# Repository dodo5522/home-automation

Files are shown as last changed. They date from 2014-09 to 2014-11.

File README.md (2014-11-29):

# Home automation

This repository is for my home automation by using Raspberry Pi and Arduino.  
The automated gardening is working now.  
Another function does not work yet.  

# System design

* Gardening monitoring
    * Written on [Qiita site](http://qiita.com/dodo5522/items/63d1efee3f70b3d5f2f6) in Japanese.
* Solar power monitoring
    * Under implementing.

# Directory structure

* documents
    * Overview, Schematics, etc.
* nodes
    * C/C++ source code working on Arduino.
    * All node will have Arduino and XBee.
* server 
    * Python source code working on Raspberry Pi.
    * Raspberry Pi will work as server to gather the all information sent by all node.

# How to use

1. Raspberry Pi as XBee cordinator
    1. Locate 'setting.conf' with below values.

            $ cat /etc/home-automation/setting.conf
            [rpiuartreceiver]
            port = /dev/ttyAMA0
            baurate = 9600
            [vegetablesplantermonitor]
            address = 0x0013a20040b44f84
            xively_api_key = xxx
            xively_feed = yyy

    2. Run the blew commands.

            $ git clone https://github.com/dodo5522/home-automation
            $ cd ./home-automation
            $ ./setup.sh
            $ sudo /etc/init.d/home-automation start

2. Arduino with XBee router
    1. Use Arduino IDE 1.5.8 or later.
    2. Add c++11 flag on Arduino toolchain setting files. You can find the file like below.

            $ find /Applications/Arduino.app -name platform.txt
            /Applications/Arduino.app/Contents/Resources/Java/hardware/arduino/avr/platform.txt
            /Applications/Arduino.app/Contents/Resources/Java/hardware/arduino/sam/platform.txt

    3. Add flag setting onto both of the above setting file.

            --- origin.txt	2014-11-03 01:01:18.000000000 +0900
            +++ modify.txt	2014-11-03 01:01:03.000000000 +0900
            @@ -17,7 +17,7 @@
             compiler.c.elf.flags=-Os -Wl,--gc-sections
             compiler.S.flags=-c -g -x assembler-with-cpp
             compiler.cpp.cmd=arm-none-eabi-g++
            -compiler.cpp.flags=-c -g -Os -w -ffunction-sections -fdata-sections -nostdlib -fno-threadsafe-statics --param max-inline-insns-single=500 -fno-rtti -fno-exceptions -Dprintf=iprintf
            +compiler.cpp.flags=-std=gnu++11 -c -g -Os -w -ffunction-sections -fdata-sections -nostdlib -fno-threadsafe-statics --param max-inline-insns-single=500 -fno-rtti -fno-exceptions -Dprintf=iprintf
             compiler.ar.cmd=arm-none-eabi-ar
             compiler.ar.flags=rcs
             compiler.objcopy.cmd=arm-none-eabi-objcopy

    4. Build and program Arduino with gardening or powerplant library.

# Sequence flow

* server
    * Initialization and termination  
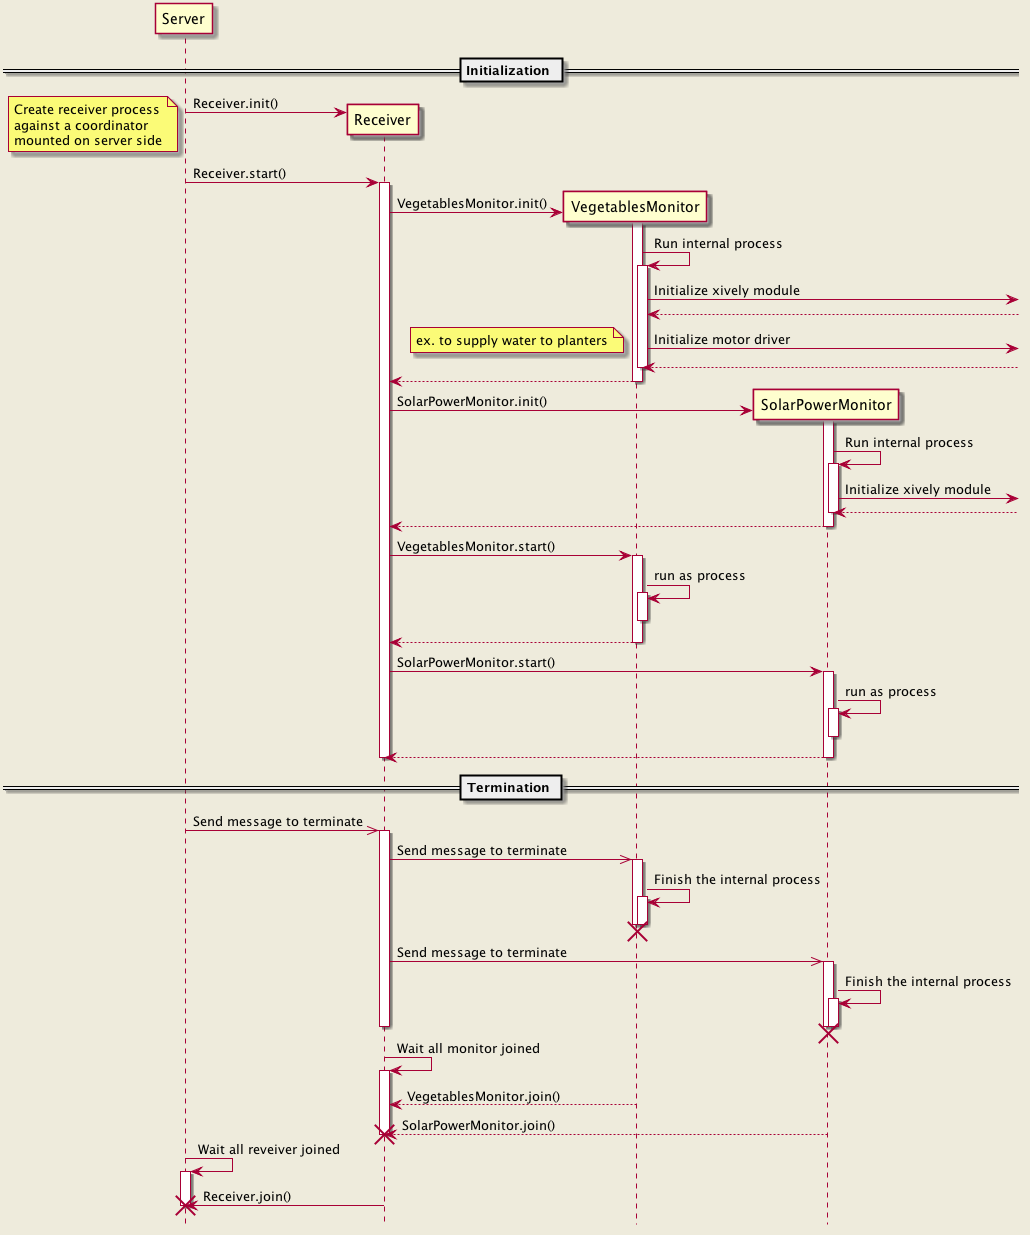
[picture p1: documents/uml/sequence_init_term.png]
initialize and terminate sequence flow
    
    * Monitoring nodes  
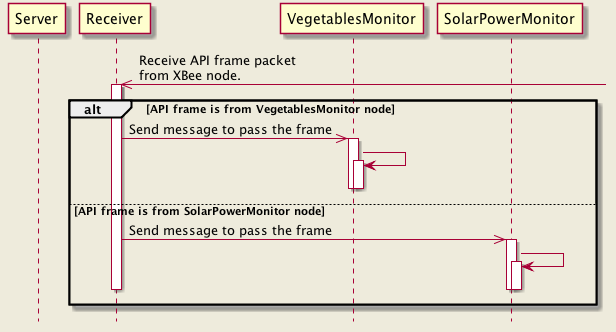
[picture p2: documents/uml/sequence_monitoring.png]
monitoring nodes


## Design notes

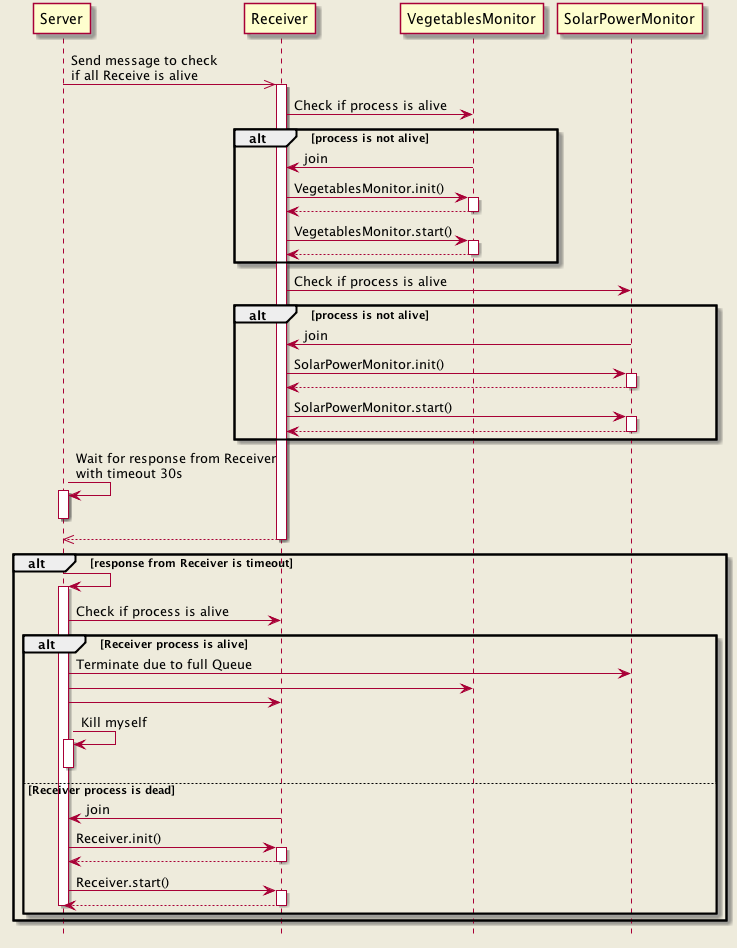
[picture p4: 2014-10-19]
documents/uml/sequence_check_alive.png

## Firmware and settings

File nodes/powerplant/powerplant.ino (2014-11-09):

/*
 Example code for my solar plant monitor.
 Editor     : Takashi Ando
 Version    : 1.0
*/
#include <Wire.h>
#include <INA226.h>
#include <Adafruit_INA219.h>
#include <XBee.h>
#include <datatype.h>
#include "powerplant.h"

#if defined(ENABLE_DEBUG_SOFT_SERIAL)
#include <SoftwareSerial.h>
#endif
#include <debug.h>

/****************************
 * IElectricPower class implementation
 ****************************/
IElectricPower::IElectricPower(char *name)
{
    strncpy(name_, name, sizeof(name_) - 1);
}

void IElectricPower::showConfig(void)
{
    DEBUG_PRINT("Name:                  "); DEBUG_PRINT(name_); DEBUG_PRINT("\n");
    DEBUG_PRINT("Measure current        "); DEBUG_PRINT(hasAvilityCurrent()); DEBUG_PRINT("\n");
    DEBUG_PRINT("Measure voltage        "); DEBUG_PRINT(hasAvilityVoltage()); DEBUG_PRINT("\n");
}

/****************************
 * MyINA226 class implementation
 ****************************/
MyINA226::MyINA226(char *name,
        uint8_t slave_address,
        float rShuntValueOhm,
        float iMaxExceptedCurrent_A,
        ina226_averages_t averages,
        ina226_busConvTime_t busConvTime,
        ina226_shuntConvTime_t shuntConvTime,
        ina226_mode_t mode)
    :IElectricPower(name),
    ina_(),
    slave_address_(slave_address),
    averages_(averages),
    busConvTime_(busConvTime),
    mode_(mode),
    rShuntValueOhm_(rShuntValueOhm),
    iMaxExceptedCurrent_A_(iMaxExceptedCurrent_A)
{
}

void MyINA226::begin(void)
{
    ina_.begin(slave_address_);
    ina_.configure(averages_, busConvTime_, shuntConvTime_, mode_);
    ina_.calibrate(rShuntValueOhm_, iMaxExceptedCurrent_A_);
}

void MyINA226::showConfig(void)
{
    IElectricPower::showConfig();
    DEBUG_PRINT("Mode:                  ");
    switch (ina_.getMode())
    {
        case INA226_MODE_POWER_DOWN:      DEBUG_PRINT("Power-Down\n"); break;
        case INA226_MODE_SHUNT_TRIG:      DEBUG_PRINT("Shunt Voltage, Triggered\n"); break;
        case INA226_MODE_BUS_TRIG:        DEBUG_PRINT("Bus Voltage, Triggered\n"); break;
        case INA226_MODE_SHUNT_BUS_TRIG:  DEBUG_PRINT("Shunt and Bus, Triggered\n"); break;
        case INA226_MODE_ADC_OFF:         DEBUG_PRINT("ADC Off\n"); break;
        case INA226_MODE_SHUNT_CONT:      DEBUG_PRINT("Shunt Voltage, Continuous\n"); break;
        case INA226_MODE_BUS_CONT:        DEBUG_PRINT("Bus Voltage, Continuous\n"); break;
        case INA226_MODE_SHUNT_BUS_CONT:  DEBUG_PRINT("Shunt and Bus, Continuous\n"); break;
        default: DEBUG_PRINT("unknown\n");
    }

    DEBUG_PRINT("Samples average:       ");
    switch (ina_.getAverages())
    {
        case INA226_AVERAGES_1:           DEBUG_PRINT("1 sample\n"); break;
        case INA226_AVERAGES_4:           DEBUG_PRINT("4 samples\n"); break;
        case INA226_AVERAGES_16:          DEBUG_PRINT("16 samples\n"); break;
        case INA226_AVERAGES_64:          DEBUG_PRINT("64 samples\n"); break;
        case INA226_AVERAGES_128:         DEBUG_PRINT("128 samples\n"); break;
        case INA226_AVERAGES_256:         DEBUG_PRINT("256 samples\n"); break;
        case INA226_AVERAGES_512:         DEBUG_PRINT("512 samples\n"); break;
        case INA226_AVERAGES_1024:        DEBUG_PRINT("1024 samples\n"); break;
        default: DEBUG_PRINT("unknown\n");
    }

    DEBUG_PRINT("Bus conversion time:   ");
    switch (ina_.getBusConversionTime())
    {
        case INA226_BUS_CONV_TIME_140US:  DEBUG_PRINT("140uS\n"); break;
        case INA226_BUS_CONV_TIME_204US:  DEBUG_PRINT("204uS\n"); break;
        case INA226_BUS_CONV_TIME_332US:  DEBUG_PRINT("332uS\n"); break;
        case INA226_BUS_CONV_TIME_588US:  DEBUG_PRINT("558uS\n"); break;
        case INA226_BUS_CONV_TIME_1100US: DEBUG_PRINT("1.100ms\n"); break;
        case INA226_BUS_CONV_TIME_2116US: DEBUG_PRINT("2.116ms\n"); break;
        case INA226_BUS_CONV_TIME_4156US: DEBUG_PRINT("4.156ms\n"); break;
        case INA226_BUS_CONV_TIME_8244US: DEBUG_PRINT("8.244ms\n"); break;
        default: DEBUG_PRINT("unknown\n");
    }

    DEBUG_PRINT("Shunt conversion time: ");
    switch (ina_.getShuntConversionTime())
    {
        case INA226_SHUNT_CONV_TIME_140US:  DEBUG_PRINT("140uS\n"); break;
        case INA226_SHUNT_CONV_TIME_204US:  DEBUG_PRINT("204uS\n"); break;
        case INA226_SHUNT_CONV_TIME_332US:  DEBUG_PRINT("332uS\n"); break;
        case INA226_SHUNT_CONV_TIME_588US:  DEBUG_PRINT("558uS\n"); break;
        case INA226_SHUNT_CONV_TIME_1100US: DEBUG_PRINT("1.100ms\n"); break;
        case INA226_SHUNT_CONV_TIME_2116US: DEBUG_PRINT("2.116ms\n"); break;
        case INA226_SHUNT_CONV_TIME_4156US: DEBUG_PRINT("4.156ms\n"); break;
        case INA226_SHUNT_CONV_TIME_8244US: DEBUG_PRINT("8.244ms\n"); break;
        default: DEBUG_PRINT("unknown\n");
    }

    DEBUG_PRINT("Max possible current:  "); DEBUG_PRINT(ina_.getMaxPossibleCurrent()); DEBUG_PRINT(" A\n");
    DEBUG_PRINT("Max current:           "); DEBUG_PRINT(ina_.getMaxCurrent());         DEBUG_PRINT(" A\n");
    DEBUG_PRINT("Max shunt voltage:     "); DEBUG_PRINT(ina_.getMaxShuntVoltage());    DEBUG_PRINT(" V\n");
    DEBUG_PRINT("Max power:             "); DEBUG_PRINT(ina_.getMaxPower());           DEBUG_PRINT(" W\n");
}

void MyINA226::showStatus(void)
{
    DEBUG_PRINT(name_);DEBUG_PRINT("\n");
    DEBUG_PRINT(" bus V: "); DEBUG_PRINT(getBusVoltage_V());   DEBUG_PRINT("\n");
    DEBUG_PRINT(" shu V: "); DEBUG_PRINT(getShuntVoltage_V()); DEBUG_PRINT("\n");
    DEBUG_PRINT(" shu A: "); DEBUG_PRINT(getShuntCurrent_A()); DEBUG_PRINT("\n");
    DEBUG_PRINT(" pwr W: "); DEBUG_PRINT(getBusPower_W());     DEBUG_PRINT("\n");
}

inline float MyINA226::getBusVoltage_V(void)
{
    return ina_.readBusVoltage();
}

inline float MyINA226::getShuntVoltage_V(void)
{
    return ina_.readShuntVoltage();
}

inline float MyINA226::getShuntCurrent_A(void)
{
    return ina_.readShuntCurrent();
}

inline float MyINA226::getBusPower_W(void)
{
    return ina_.readBusPower();
}

/****************************
 * MyINA219 class implementation
 ****************************/
MyINA219::MyINA219(char *name, uint8_t slave_address)
    :IElectricPower(name),
    ina_(slave_address)
{
}

void MyINA219::begin(void)
{
    ina_.begin();
}

void MyINA219::showStatus(void)
{
    DEBUG_PRINT(name_);DEBUG_PRINT("\n");
    DEBUG_PRINT(" bus V: "); DEBUG_PRINT(getBusVoltage_V());   DEBUG_PRINT("\n");
    DEBUG_PRINT(" shu V: "); DEBUG_PRINT(getShuntVoltage_V()); DEBUG_PRINT("\n");
    DEBUG_PRINT(" cur A: "); DEBUG_PRINT(getShuntCurrent_A()); DEBUG_PRINT("\n");
}

float MyINA219::getBusVoltage_V(void)
{
    return ina_.getBusVoltage_V();
}

float MyINA219::getShuntVoltage_V(void)
{
    return ina_.getShuntVoltage_mV()/1000.0;
}

float MyINA219::getShuntCurrent_A(void)
{
    return ina_.getCurrent_mA()/1000.0;
}

/****************************
 * Macro definition
 ****************************/
//const uint8_t INA226_ADDRESS  = 0x40;
const uint8_t INA226_11_ADDRESS = 0x45;
const uint8_t INA226_DD_ADDRESS = 0x4a;
const uint8_t INA226_CC_ADDRESS = 0x4f;

//const uint8_t INA219_ADDRESS    = 0x40;
const uint8_t INA219_A0_ADDRESS   = 0x41;
const uint8_t INA219_A1_ADDRESS   = 0x44;
const uint8_t INA219_A0A1_ADDRESS = 0x45;

const int LED_SWITCH_PIN = 2;

/****************************
 * global variables
 ****************************/
#if !defined(ENABLE_DEBUG_HARD_SERIAL)
static XBee myXBee = XBee();
static XBeeAddress64 addrContributor = XBeeAddress64(XBEE_ADDRESS_H_COORDINATOR, XBEE_ADDRESS_L_COORDINATOR);
#endif

static MyINA226 battery = MyINA226("battery", INA226_CC_ADDRESS);
static MyINA226 solar = MyINA226("solar panel", INA226_DD_ADDRESS);
//static MyINA219 conv = MyINA219("converter", INA219_A0A1_ADDRESS);

static IElectricPower *powerSensors[] =
{
    static_cast<IElectricPower*>(&battery),
    static_cast<IElectricPower*>(&solar),
//    static_cast<IElectricPower*>(&conv)
};

static unsigned long mainLoopInterval = MAIN_INTERVAL_MSEC;

/****************************
 * internal functions
 ****************************/
boolean isTriggerToPost(void)
{
    static unsigned long previous_tick_count = millis();
    unsigned long current_tick_count = millis();

    if(current_tick_count < previous_tick_count)
    {
        previous_tick_count = current_tick_count;
        return false;
    }
    else if(current_tick_count - previous_tick_count < mainLoopInterval)
    {
        return false;
    }

    previous_tick_count = current_tick_count;
    return true;
}

void setup(void)
{
    setup_debug();

#if !defined(ENABLE_DEBUG_HARD_SERIAL)
    Serial.begin(XBEE_SERIAL_BAURATE);
    myXBee.setSerial(Serial);
#endif

    //FIXME: LED power on/off switch control.
    pinMode(LED_SWITCH_PIN, OUTPUT);
    digitalWrite(LED_SWITCH_PIN, LOW);

    for(auto sensor : powerSensors)
    {
        sensor->begin();
    }

#if (defined(ENABLE_DEBUG_HARD_SERIAL) || defined(ENABLE_DEBUG_SOFT_SERIAL))
    delay(5000);

    // Show configuration
    for(auto sensor : powerSensors)
    {
        sensor->showConfig();
    }
#endif
}

void loop(void)
{
    enum class SensorType : uint8_t
    {
        VOLTAGE = 0,
        CURRENT,
        WAT,
        MAX
    };

    //FIXME: LED power on/off switch control.
    static boolean led_on = false;
    SENSOR_DATA sensor_data[sizeof(powerSensors)/sizeof(IElectricPower*)][static_cast<int>(SensorType::MAX)] =
    {
        {
            {{'V', 'O', 'L'}, '0', 100, 0}, // bus voltage
            {{'C', 'U', 'R'}, '0', 100, 0}, // shunt current
            {{'W', 'A', 'T'}, '0', 100, 0}, // power
        },
        {
            {{'V', 'O', 'L'}, '0', 100, 0}, // bus voltage
            {{'C', 'U', 'R'}, '0', 100, 0}, // shunt current
            {{'W', 'A', 'T'}, '0', 100, 0}, // power
        },
    };

    digitalWrite(LED_SWITCH_PIN, led_on ? HIGH : LOW);
    led_on = !led_on;

    if (isTriggerToPost() != true)
    {
        return;
    }

#if (defined(ENABLE_DEBUG_HARD_SERIAL) || defined(ENABLE_DEBUG_SOFT_SERIAL))
    for(auto sensor : powerSensors)
    {
        sensor->showStatus();
    }
#endif

    for(uint8_t i = 0; i < sizeof(powerSensors)/sizeof(IElectricPower*); i++)
    {
        //FIXME: INA219 will crash.
        sensor_data[i][0].value = static_cast<int32_t>(sensor_data[i][0].multiple * static_cast<MyINA226*>(powerSensors[i])->getBusVoltage_V());
        sensor_data[i][1].value = static_cast<int32_t>(sensor_data[i][1].multiple * static_cast<MyINA226*>(powerSensors[i])->getShuntCurrent_A());
        sensor_data[i][2].value = static_cast<int32_t>(sensor_data[i][2].multiple * static_cast<MyINA226*>(powerSensors[i])->getBusPower_W());
    }

#if !defined(ENABLE_DEBUG_HARD_SERIAL)
    ZBTxRequest myTxRequest = ZBTxRequest(
            addrContributor,
            (uint8_t*)sensor_data,
            sizeof(sensor_data));

    myXBee.send(myTxRequest);
#endif
}

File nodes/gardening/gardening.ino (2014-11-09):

/*
 Example code for my gardening.
 Editor     : Takashi Ando
 Version    : 1.0

 Hardware Connections (Breakoutboard to Arduino Pro Mini):
 -VCC = 3.3V
 -GND = GND
 -SDA = A4
 -SCL = A5
*/
#include <Wire.h>
#include <TSL2561.h>
#include <HTU21D.h>
#include <MOISTURE_SEN0114.h>
#include <XBee.h>
#include <datatype.h>
#include "gardening.h"

#if defined(ENABLE_DEBUG_SOFT_SERIAL)
#include <SoftwareSerial.h>
#endif
#include <debug.h>

/****************************
 * Macro definition
 ****************************/

/****************************
 * Global variables
 ****************************/

static XBee myXBee = XBee();
static XBeeAddress64 addrContributor = XBeeAddress64(XBEE_ADDRESS_H_COORDINATOR, XBEE_ADDRESS_L_COORDINATOR);

static MOISTURE_SEN0114 myMoisture0 = MOISTURE_SEN0114(MOIST0_READ_PIN);
static MOISTURE_SEN0114 myMoisture1 = MOISTURE_SEN0114(MOIST1_READ_PIN);
static HTU21D myHumidity = HTU21D();
static TSL2561 myLight = TSL2561();

static unsigned int lightIntegrationTime = 0;
static unsigned long mainLoopInterval = MAIN_INTERVAL_MSEC;

/****************************
 * internal functions
 ****************************/
boolean isTriggerToPost(void)
{
    static unsigned long previous_tick_count = millis();
    unsigned long current_tick_count = millis();

    if(current_tick_count < previous_tick_count)
    {
        previous_tick_count = current_tick_count;
        return false;
    }
    else if(current_tick_count - previous_tick_count < mainLoopInterval)
    {
        return false;
    }

    previous_tick_count = current_tick_count;
    return true;
}

void flashLed(int times, int wait)
{
    static const int errorLed = 13;

    for (int i = 0; i < times; i++)
    {
        digitalWrite(errorLed, HIGH);
        delay(wait);
        digitalWrite(errorLed, LOW);

        if (i + 1 < times)
            delay(wait);
    }
}

void indicateStatusXBee(XBee &myXBee)
{
    uint8_t api_id = 0;
    uint8_t delivery_status = 0;
    bool error = false;

    // if there is no problem on conmunication, LED is not lighten.
    ZBTxStatusResponse txStatus = ZBTxStatusResponse();

    // after sending a tx request, we expect a status response
    // wait up to half second for the status response
    if (myXBee.readPacket(500))
    {
        // should be a znet tx status
        api_id = myXBee.getResponse().getApiId();
        if (api_id != ZB_TX_STATUS_RESPONSE)
        {
            DEBUG_PRINT("Error: API ID is ");DEBUG_PRINT(api_id);DEBUG_PRINT("\n");
            flashLed(5, 500);
            return;
        }

        myXBee.getResponse().getZBTxStatusResponse(txStatus);

        // get the delivery status, the fifth byte
        delivery_status = txStatus.getDeliveryStatus();
        if (delivery_status != SUCCESS)
        {
            DEBUG_PRINT("Error: Delivery status is ");DEBUG_PRINT(delivery_status);DEBUG_PRINT("\n");
            flashLed(4, 500);
        }
    }
    else
    {
        error = myXBee.getResponse().isError();
        if (error)
        {
            DEBUG_PRINT("Error: Response error.");DEBUG_PRINT("\n");
            flashLed(3, 500);
        }
        else
        {
            DEBUG_PRINT("Error: Another.");DEBUG_PRINT("\n");
            flashLed(2, 50);
        }
    }
}

/****************************
 * main routine
 ****************************/
void setup()
{
    setup_debug();

#if !defined(ENABLE_DEBUG_HARD_SERIAL)
    Serial.begin(XBEE_SERIAL_BAURATE);
    myXBee.setSerial(Serial);
#endif

    myHumidity.begin();
    myLight.begin();

    // setTiming() will set the third parameter (ms) to the
    // requested integration time in ms (this will be useful later):
    // The sensor will now gather light during the integration time.
    // After the specified time, you can retrieve the result from the sensor.
    myLight.setTiming(LIGHT_GAIN, LIGHT_INTEGRATION_TIME_INDEX , lightIntegrationTime);
    myLight.setPowerUp();

    if(mainLoopInterval < lightIntegrationTime)
        mainLoopInterval = lightIntegrationTime;
}

void loop()
{
    unsigned int lightData0 = 0;
    unsigned int lightData1 = 0;
    double nowLuxDouble = 0.0;
    SENSOR_DATA sensorData[E_SENSOR_MAX] =
    {
        {{'L', 'U', 'X'}, '0', 10, 0},
        {{'M', 'O', 'I'}, '0', 10, 0}, // for small planter
        {{'M', 'O', 'I'}, '1', 10, 0}, // for large planter
        {{'H', 'U', 'M'}, '0', 10, 0},
        {{'T', 'M', 'P'}, '0', 10, 0},
    };

    if (isTriggerToPost() != true)
        return;

    if (myLight.getData(lightData0, lightData1))
    {
        // Perform lux calculation:
        myLight.getLux(LIGHT_GAIN, lightIntegrationTime, lightData0, lightData1, nowLuxDouble);
        sensorData[E_SENSOR_LUMINOSITY].value =
            (int32_t)(sensorData[E_SENSOR_LUMINOSITY].multiple * nowLuxDouble);
    }

    sensorData[E_SENSOR_TEMPERATURE].value =
        (int32_t)(sensorData[E_SENSOR_TEMPERATURE].multiple * myHumidity.readTemperature());
    sensorData[E_SENSOR_HUMIDITY].value =
        (int32_t)(sensorData[E_SENSOR_HUMIDITY].multiple * myHumidity.readHumidity());
    sensorData[E_SENSOR_MOISTURE0].value =
        (int32_t)(sensorData[E_SENSOR_MOISTURE0].multiple * myMoisture0.getMoisturePercent());
    sensorData[E_SENSOR_MOISTURE1].value =
        (int32_t)(sensorData[E_SENSOR_MOISTURE1].multiple * myMoisture1.getMoisturePercent());

    ZBTxRequest myTxRequest = ZBTxRequest(
            addrContributor,
            (uint8_t*)sensorData,
            sizeof(sensorData));

#if !defined(ENABLE_DEBUG)
    myXBee.send(myTxRequest);

    // this function takes 500ms as max when timeout error.
    indicateStatusXBee(myXBee);
#endif

    DEBUG_PRINT("Luminosity:");  DEBUG_PRINT(sensorData[E_SENSOR_LUMINOSITY].value /(float)sensorData[E_SENSOR_LUMINOSITY].multiple); DEBUG_PRINT("[lm]\n");
    DEBUG_PRINT("Moisture0 :");  DEBUG_PRINT(sensorData[E_SENSOR_MOISTURE0].value  /(float)sensorData[E_SENSOR_MOISTURE0].multiple);  DEBUG_PRINT("[%]\n");
    DEBUG_PRINT("Moisture1 :");  DEBUG_PRINT(sensorData[E_SENSOR_MOISTURE1].value  /(float)sensorData[E_SENSOR_MOISTURE1].multiple);  DEBUG_PRINT("[%]\n");
    DEBUG_PRINT("Humidity :");   DEBUG_PRINT(sensorData[E_SENSOR_HUMIDITY].value   /(float)sensorData[E_SENSOR_HUMIDITY].multiple);   DEBUG_PRINT("[%]\n");
    DEBUG_PRINT("Temperature :");DEBUG_PRINT(sensorData[E_SENSOR_TEMPERATURE].value/(float)sensorData[E_SENSOR_TEMPERATURE].multiple);DEBUG_PRINT("[C]\n");
}

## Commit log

2014-08-20 Add original libraries and sample ino files.
2014-08-21 Add library for moisture sensor.
2014-08-27 To read sensors of moisture, humidity, and temperature.
2014-09-01 Send values of all sensor moisture, humidity, and temperature.
2014-09-01 Replace 2 spaces to 4 spaces.
    [gardening.ino]
2014-09-02 Define new struct to store and post the data of sensor.
2014-09-04 Implement to get light sensor values, but not tested yet and xbee protocol is not implemented yet.
2014-09-05 Implement to send the value of light sensor to remote XBee.
2014-09-05 To get all sensor value after delay().
2014-09-07 Add schematic of all system.
    [system.fzz]
2014-09-09 Fix: To be able to print each sensor value.
    [gardening.ino]
2014-09-09 Modify LED flash indicator.
2014-09-09 Modify XBEE_API switch to be able to build with not setting it.
2014-09-16 Make table of sensors to be clear.
2014-09-16 Integrate sensor value as signed long.
2014-09-16 Use millis() to measure the time of main loop but not delay().
2014-09-16 To send all sensor data as only one frame.
2014-09-20 Add one more moisture sensor.
2014-09-20 Move files into documents, nodes, and server.
    [system.fzz]
2014-09-20 nodes/libraries/XBee
    Remove XBee library directory.
    [server.fzz]
2014-09-21 Devide system schematic to each file.
    [node_center.fzz, node_garden.fzz, node_solar.fzz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]
2014-09-24 Add fritzing files for HTU21D.
    [Hookup.fzz]
2014-09-24 Update schematic files for arround arduino and sensor board.
    [node_center.fzz, node_garden.fzz]
2014-09-24 Update MOISTURE_SEN0114 class constructor to pass the min/max sensor values and calculate percentage with them.
2014-09-24 Update moisture sensor pins due to the latest schematics.
2014-09-25 Remove sendData buffer and send sensorData via XBee directly for issue #3.
    [gardening.ino]
2014-09-30 Add SensorData, XBeeNode, and XBeeReceiver class.
2014-09-30 Modify schematic for garden node.
    [node_garden.fzz]
2014-10-05 Add UML documents.
    [config.txt]
2014-10-05 To use logging module to close issue #6.
    [xbeereceiver.py]
2014-10-06 Add sequence flow diagram of all process works on RaspberryPi.
2014-10-06 Change background color.
    [config.txt]
2014-10-11 Add submodule for INA219 driver.
2014-10-11 Add power plant sample code to measure the current with INA219.
2014-10-11 Add submodule for INA226 driver.
2014-10-12 Add sample code to measure the current & voltage with INA226.
2014-10-12 Modify unit of current from mA to A.
2014-10-13 Add process.BaseProcess to be based process with message handlers in this server programs for issue #4.
    [process.py]
2014-10-14 Replace print to logging.debug.
    [process.py]
2014-10-16 Halt xbee wait frame thread before terminating process.
2014-10-16 Monitor instance posts sensor data if the source address equals to monitoring address.
2014-10-16 To be able to post sensor data to Xively.
2014-10-17 Fix issue of missing __init__ call of parent class.
    [xbeeparser.py]
2014-10-19 Fix debug message's bug.
    [xbeeparser.py]
2014-10-19 Test make environment of plantuml sequence flow diagram generation.
2014-10-19 Add sequence flow to check if all process is alive or not.
2014-10-19 Add sequence flow to monitor nodes.
2014-10-28 Add sample setting.conf file.
2014-10-30 Fix import error to move base_modules to base.
    [xbeereceiver.py]
2014-11-01 Add datatype.h to share the definition of SENSOR_DATA.
2014-11-01 Add debug.h to share the definition of debug print macro.[D
2014-11-01 To use debug.h and datatype.h on powerplant node. issue #20.
    [gardening.ino, powerplant.ino]
2014-11-01 To use LED pin definition.
2014-11-02 Implement to read current/voltage sensor values.
2014-11-02 Add multiple value as sensor data structure.
2014-11-02 Update README.txt to add Arduino toolchain tips for C++11.
2014-11-09 Correct datatype casting on gardening node.
    [gardening.ino]
2014-11-09 Add submodule Arduino-Makefile.
2014-11-09 Add makefile for power plant arduino.
2014-11-09 Add MCU, F_CPU, HEX_MAXIMUM_SIZE due to arduino-mk-vars.md because boards.txt does not have enough information pro/pro mini.
2014-11-09 To upload hex file to arduino by make upload command.
2014-11-09 Implement a function to send sensor data to XBee coordinator.
2014-11-09 Add makefile for gardening arduino.
2014-11-09 To set debug switch with make option.
2014-11-12 Revert the struct format from 4sll to 4sl for gardening.
    [xbeeparser.py]
2014-11-29 Fix issue #22. Cannot start and stop home-automation service.
    [process.py, xbeereceiver.py]
2014-12-26 Implement test case of BaseProcess class.
2014-12-27 Add test case for Twitter class.
2014-12-27 Divide test case class.
2015-05-18 To use Arduino IDE 1.6.4
2016-08-27 Update xbee-arduino repository.
